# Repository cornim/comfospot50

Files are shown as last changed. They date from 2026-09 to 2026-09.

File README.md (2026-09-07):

<!-- SPDX-FileCopyrightText: 2026 cornim -->
<!-- SPDX-License-Identifier: CC-BY-SA-4.0 -->

# ComfoSpot 50 Home Assistant integration

This project integrates a ComfoSpot 50 into Home Assistant through a custom
ESPHome component and a custom-designed PCB board. The component connects an
ESP32-C3 to the existing panel, reading its LEDs and electrically simulating
short and long presses of the `+` and `-` buttons.

The component is in `components/comfospot/`. Complete ESPHome examples are in
`examples/`, installation and troubleshooting documentation is in `docs/`, and
wiring and the controller board design are in `hardware/`.

## Installation

See [`docs/installation.md`](docs/installation.md) for software flashing, board
power selection, hardware installation, security, and safety instructions.

## Safety and no warranty

This project is provided "as is", without warranty of any kind, express or
implied, including but not limited to warranties of merchantability, fitness
for a particular purpose, safety, and non-infringement. Use of this project
may involve electrical, fire, ventilation, property-damage, personal-injury,
or equipment-damage risks. You are responsible for verifying the design,
electrical compatibility, isolation, installation, operation, and compliance
with applicable laws and regulations.

Do not connect this circuit to a ventilation appliance or mains-related
equipment unless the installation has been reviewed and performed by a
suitably qualified person. Verify voltage levels, current limits, isolation,
grounding, enclosure requirements, and failure behavior before construction or
use. This project is not a safety control and must not be used where its
failure could create an unsafe condition.

## Unofficial project

This is an independent project and is not affiliated with, endorsed by, or
approved by Zehnder Group. "Zehnder" and "ComfoSpot" are trademarks of their
respective owners and are used only to identify the compatible product.

The original idea for this project and the reverse engineering of the ComfoSpot
50 were done by [lorenzspenger](https://github.com/lorenzspenger) in the
[`comfospot-50`](https://github.com/lorenzspenger/comfospot-50) project. This
repository's implementation was built from scratch because the original project
does not support standby mode.

## Fan levels

The fan exposes four active levels plus standby:

- `0`: standby, fans off
- `1` through `4`: the four ComfoSpot fan levels

In Home Assistant, standby is represented by the fan being off. The diagnostic
`Current Fan Speed` sensor reports the last confirmed numeric level `0` through
`4`. It remains unavailable only while the panel's display state is ambiguous,
such as immediately after boot with all LEDs off; it keeps reporting the last
known active speed while the display is temporarily dark for energy-saving mode.

The component reads the physical panel during boot and does not turn the unit
on automatically. Physical short button presses are synchronized back to Home
Assistant. Remote commands read and validate the panel directly, retrying when
the first press only wakes a sleeping display. Direction changes use the
observed panel marker and a bounded long-press operation. Filter runtime counts
confirmed active fan time and is persisted periodically and after a confirmed
filter reset.

## Hardware

The controller board design and detailed panel wiring documentation are in
[`hardware/README.md`](hardware/README.md) and
[`hardware/wiring.md`](hardware/wiring.md).

## Getting hardware

Detailed instructions for ordering the controller board are in
[`hardware/HOW_TO_ORDER.md`](hardware/HOW_TO_ORDER.md). The minimum
order is five boards, so if you need fewer boards, or if you have additional
boards to sell, feel free to open an issue in this repository to arrange a
purchase or sale.

## ESPHome configuration

The example downloads the component from this repository's `main` branch:

```yaml
external_components:
  - source:
      type: git
      url: https://github.com/cornim/comfospot50
      ref: main
    components: [comfospot]
```

See `examples/comfospot.yaml` for a complete example. It requires encrypted
API access, an OTA password, Wi-Fi credentials, and a non-empty fallback access
point password supplied through a local `examples/secrets.yaml`. Never commit
that file or any other deployment secrets.

## Building and testing

Build and run the host-side tests with:

```text
cmake -S . -B build
cmake --build build
ctest --test-dir build --output-on-failure
```

The live ESPHome API test runner is an optional Python end-to-end test suite in
`tests/e2e_comfospot.py`. It connects to a flashed ComfoSpot device over the
native ESPHome API, discovers its entities, exercises fan controls and state
reporting, and records a test report and device logs. It requires the
development dependency listed in `requirements-dev.txt`. The runner uses
credentials supplied through environment variables and never stores the API key
in test artifacts. See [`docs/e2e-testing.md`](docs/e2e-testing.md) for setup
and usage.

## Repository licensing

- ESPHome component source and tests: `GPL-3.0-or-later`.
- Project-authored schematic, PCB layout, wiring diagram, and hardware design:
  `CERN-OHL-S-2.0`.
- Project-authored documentation and timing notes: `CC-BY-SA-4.0`.
- Embedded component-library data and any other third-party material remain
  subject to their applicable terms; see `THIRD_PARTY_NOTICES.md`.

The project copyright holder is [`cornim`](https://github.com/cornim).
Licensing, security, and contribution questions are handled through GitHub for
this repository.

The license files are in `LICENSES/`. The root `LICENSE` is the GPLv3-or-later
license used for the software portion of the repository. The scoped notices in
the hardware and documentation directories define the other scopes.

No manufacturer datasheet PDFs or product manuals are distributed by this
repository. Consult the relevant manufacturer or distributor for current
documentation.

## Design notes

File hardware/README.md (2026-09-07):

<!-- SPDX-FileCopyrightText: 2026 cornim -->
<!-- SPDX-License-Identifier: CERN-OHL-S-2.0 -->

# Hardware

The schematic and PCB in this directory are the project-authored controller
board design. The board is intended to interface an ESP32-C3 with the existing
ComfoSpot panel.
See [`wiring.md`](wiring.md) for the panel connections and electrical interface
notes.

## License scope

The project-authored schematic connectivity, PCB layout, routing, board
outline, wiring diagram, and related hardware documentation are released under
the CERN Open Hardware Licence Version 2 - Strongly Reciprocal, found in
`../LICENSES/CERN-OHL-S-2.0.txt`.

The KiCad files contain embedded component symbols and footprints selected from
the JLCPCB/LCSC/EasyEDA component ecosystem and Würth's component library.
Those embedded third-party elements are not relicensed by the project license.
Their provenance and applicable terms are described in
`../THIRD_PARTY_NOTICES.md`.

The standard KiCad library elements used by the design remain subject to the
KiCad library license and its design exception.

The project copyright holder is [`cornim`](https://github.com/cornim).
Licensing and contribution questions can be handled through GitHub for this
repository.

Source location for the covered hardware design is the GitHub repository
containing this file. Preserve this source location and the applicable notices
when conveying the hardware design or a product made from it.

## Deliberate omissions

3D model references are not included in the public PCB file. This keeps the
design portable and avoids distributing model files that are not needed for
schematic review, PCB editing, or fabrication. The board remains a complete
2D KiCad design and retains its footprints, pads, nets, routing, vias, zones,
silkscreen, and outline.

Manufacturer datasheet PDFs are not included. Use the manufacturer or
distributor source for current component documentation. The LCSC identifiers
in the BOM are retained as manufacturing-selection information.

The `hardware/production/comfospot50_full.zip` archive contains Gerber and
drill fabrication output. It is generated output and does not contain the
component library or 3D model files.

## Safety and no warranty

The hardware is provided "as is", without warranty of any kind, express or
implied, including warranties of merchantability, fitness for a particular
purpose, safety, and non-infringement. Verify voltage levels, current limits,
isolation, grounding, enclosure requirements, creepage, clearance, and failure
behavior before construction or use. A qualified person must review and
perform any connection to an installed ventilation appliance or mains-related
equipment.

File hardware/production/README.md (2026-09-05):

<!-- SPDX-FileCopyrightText: 2026 cornim -->
<!-- SPDX-License-Identifier: CERN-OHL-S-2.0 -->

# Production Output

The Gerber and drill archive is generated from the project hardware design.
The LCSC identifiers in `bom.csv` identify the selected manufacturing parts;
they are not a license for third-party CAD or datasheet material.

The production outputs are provided without warranty. Verify the board stackup,
component substitutions, assembly orientation, electrical clearances, and
applicable manufacturing requirements before ordering.

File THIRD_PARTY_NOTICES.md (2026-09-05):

<!-- SPDX-FileCopyrightText: 2026 cornim -->
<!-- SPDX-License-Identifier: CC-BY-SA-4.0 -->

# Third-Party Notices

The project licenses apply only to project-authored material within the scope
described in `README.md`, `hardware/README.md`, and the source-file notices.
Third-party material remains subject to its own terms.

## JLCPCB, LCSC, and EasyEDA component data

The KiCad schematic and PCB contain embedded symbols and footprints originating
from or based on component data available through the JLCPCB/LCSC/EasyEDA
ecosystem. The following LCSC identifiers are retained as component-selection
and manufacturing references:

```text
C25804       UNI-ROYAL 0603WAF1002T5E
C106214      YAGEO CC0603KRX5R6BB105
C14663       YAGEO CC0603KRX7R9BB104
C13585       Samsung CL31A106KBHNNNE
C5672        Samsung CL31A226KPHNNNE
C2944070     Espressif ESP32-C3-WROOM-02-H4
C5369647     YLPTEC K7803-1000R3
C976701      KEFA KF239-5.08-2P
C82942       MICRONE ME6211C33M5G-N
C963206      G-Switch MK-12C02-G020
C114765      YAGEO RC0402FR-0722RL
C269716      Tyohm RMC06035.1K1%N
C18384       Littelfuse RXEF030
C2482        MDD SS110
C318884      XKB TS-1187A-B-A-B
C393939      SHOU HAN TYPE-C16PIN
C7519        ST USBLC6-2SC6
```

The identifiers and component names do not constitute a license to reproduce
the source library data. No JLCPCB/LCSC/EasyEDA datasheet PDFs are distributed
here. Obtain current component documentation directly from the applicable
manufacturer or distributor.

Relevant source and terms pages include:

- [EasyEDA Terms and Conditions](https://easyeda.com/page/legal)
- [LCSC Terms and Conditions](https://www.lcsc.com/help/terms-and-conditions)
- [JLCPCB Terms and Conditions](https://jlcpcb.com/help/article/Terms-%26-Conditions)
- [easyeda2kicad converter](https://github.com/uPesy/easyeda2kicad.py), licensed separately under AGPL-3.0

The converter's license applies to the converter software, not automatically to
component data retrieved through the converter.

## Würth Elektronik library data

The two WR-MM connector footprints and their embedded symbol data correspond to
the official Würth Elektronik KiCad library:

- [Würth Elektronik KiCad Library](https://github.com/WurthElektronik/KiCad-Library)
- [License terms](https://github.com/WurthElektronik/KiCad-Library/blob/master/License_Terms_WE_KiCad_library.pdf)
- [Disclaimer](https://github.com/WurthElektronik/KiCad-Library/blob/master/Disclaimer_WE_KiCad_library.pdf)

The source repository was inspected at commit
`40adcee44afdab5f4ed8038699f78bd784e0f594` on 2026-09-04. The exact upstream
files matching the connector identifiers were present at that revision.

The relevant parts are:

```text
J_Wurth_WR-MM_690357101472
J_Wurth_WR-MM_690368171472
```

Würth retains ownership of its models. Its terms permit creating and sharing
designs using the models, subject to the separate license terms, but do not
grant a general patent, trademark, or unrestricted sublicensing license. Any
Würth model or library file distributed separately must retain the applicable
Würth notices and must be clearly marked if modified.

## KiCad libraries

The standard KiCad elements used by the project include `power:GND` and the
standard test-point symbol and footprint. KiCad libraries are licensed under
CC BY-SA 4.0 with an exception for electronic designs and generated files that
use the library data.

- [KiCad library license](https://www.kicad.org/libraries/license/)

## Build-time software dependencies

The ESPHome component is intended to be built by ESPHome and is not a copy of
ESPHome itself. ESPHome is available from
[its repository](https://github.com/esphome/esphome) under the MIT License.

The live test runner uses `aioesphomeapi`, declared in
`requirements-dev.txt`. It is available from
[its repository](https://github.com/esphome/aioesphomeapi) under the MIT
License. These dependencies are obtained by users or CI and are not bundled
in this repository.

## Project copyright and contact

Project copyright holder: [`cornim`](https://github.com/cornim). Licensing
questions and notices can be submitted through GitHub for this repository.

## Manufacturer names and trademarks

Manufacturer names, product names, part numbers, and trademarks identify the
components compatible with the design. They do not imply endorsement or
affiliation. Zehnder and ComfoSpot are trademarks of their respective owners.

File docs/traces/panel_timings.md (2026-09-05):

<!-- SPDX-FileCopyrightText: 2026 cornim -->
<!-- SPDX-License-Identifier: CC-BY-SA-4.0 -->

# ComfoSpot Panel Timings

These timings were measured on the live ComfoSpot panel through the ESPHome
verbose scan log. The panel was sampled every 50 ms, so individual transition
timestamps have an uncertainty of approximately one scan interval. Times in
each measurement are relative to the start of that monitor run.

## Measurement 1: Normal Button Press

One physical `+` press was monitored while the panel was active.

| Event | Time |
| --- | ---: |
| Button pressed | 5.832 s |
| Button released | 6.152 s |
| Button duration | 0.319 s |
| Fan LEDs on | 6.195 s |
| Fan LEDs off | 15.237 s |
| Fan LED duration | 9.043 s |

LED mask sequence:

```text
0x00 -> 0x01 -> 0x00
```

The LED indication started approximately 43 ms after the button release.

## Measurement 2: Wake From Standby

One short physical `+` press woke the panel from standby. The standby wake
acknowledgement lights all four fan LEDs.

| Event | Time |
| --- | ---: |
| Button pressed | 5.072 s |
| Button released | 5.278 s |
| Button duration | 0.206 s |
| All fan LEDs on (`0x0F`) | 5.278 s |
| All fan LEDs off (`0x00`) | 6.467 s |
| All-LED duration | 1.189 s |

LED mask sequence:

```text
0x00 -> 0x0F -> 0x00
```

The all-LED frame started at the observed button-release transition, within
the 50 ms measurement resolution.

## Measurement 3: Standby Wake and Intake

The panel was first woken with a short `+` press and then changed to Intake
with a long `+` press.

### Button timings

| Press | Start | End | Duration |
| --- | ---: | ---: | ---: |
| Wake press (`+`) | 6.955 s | 7.120 s | 0.166 s |
| Intake press (`+`) | 7.689 s | 15.777 s | 8.088 s |

### Fan LED transitions

| Time | Transition |
| ---: | --- |
| 7.178 s | `0x00 -> 0x03` |
| 15.198 s | `0x03 -> 0x08` |
| 15.664 s | `0x08 -> 0x00` |
| 16.184 s | `0x00 -> 0x08` |
| 16.689 s | `0x08 -> 0x00` |
| 17.266 s | `0x00 -> 0x08` |
| 17.726 s | `0x08 -> 0x00` |
| 18.182 s | `0x00 -> 0x03` |
| 21.220 s | `0x03 -> 0x08` |
| 21.629 s | `0x08 -> 0x00` |

The primary Intake marker started 7.509 s after the long press began, or
0.579 s before it was released. The first marker sequence returned to the
normal Speed-2 display (`0x03`) 2.405 s after the long press was released.

Relative to the end of the long press:

| Relative time | Transition |
| ---: | --- |
| -0.579 s | `0x03 -> 0x08` |
| -0.113 s | `0x08 -> 0x00` |
| +0.407 s | `0x00 -> 0x08` |
| +0.912 s | `0x08 -> 0x00` |
| +1.489 s | `0x00 -> 0x08` |
| +1.949 s | `0x08 -> 0x00` |
| +2.405 s | `0x00 -> 0x03` |
| +5.443 s | `0x03 -> 0x08` |
| +5.852 s | `0x08 -> 0x00` |

The normal Speed-2 display is `0x03`; the Intake marker is `0x08` alternating
with `0x00`.

## Measurement 4: Intake to Exchange

The panel was woken with a short `+` press and then changed from Intake back to
Exchange with a long `+` press.

### Button timings

| Press | Start | End | Duration |
| --- | ---: | ---: | ---: |
| Wake press (`+`) | 3.798 s | 4.004 s | 0.207 s |
| Exchange press (`+`) | 4.616 s | 12.675 s | 8.059 s |

### Fan LED transitions

| Time | Transition |
| ---: | --- |
| 4.004 s | `0x00 -> 0x03` |
| 4.313 s | `0x03 -> 0x08` |
| 4.768 s | `0x08 -> 0x00` |
| 5.330 s | `0x00 -> 0x08` |
| 5.832 s | `0x08 -> 0x00` |
| 6.353 s | `0x00 -> 0x08` |
| 6.862 s | `0x08 -> 0x00` |
| 7.332 s | `0x00 -> 0x03` |
| 19.302 s | `0x03 -> 0x00` |

The Intake marker sequence completed before the long press ended. The normal
Speed-2 display returned 5.343 s before release and remained visible for
6.627 s afterward. The later `0x03 -> 0x00` transition occurred 6.627 s after
release, when the display entered Energy-Saving mode.

LED mask sequence:

```text
0x00 -> 0x03 -> 0x08 -> 0x00 -> 0x08 -> 0x00
     -> 0x08 -> 0x00 -> 0x03 -> 0x00
```

No `0x0F` all-LED standby acknowledgement was observed in this measurement.

## Measurement 5: Speed 2 to Speed 1 and Energy-Saving

The panel was woken with a short `-` press and then reduced from Speed 2 to
Speed 1 with a short `-` press. The measurement ended when the display entered
Energy-Saving mode.

### Button timings

| Press | Start | End | Duration |
| --- | ---: | ---: | ---: |
| Wake press (`-`) | 3.082 s | 3.238 s | 0.156 s |
| Speed reduction (`-`) | 3.963 s | 4.064 s | 0.101 s |

### Fan LED transitions

| Time | Transition |
| ---: | --- |
| 3.238 s | `0x00 -> 0x03` |
| 4.064 s | `0x03 -> 0x01` |
| 13.296 s | `0x01 -> 0x00` |

The Speed-1 display (`0x01`) remained visible for 9.232 s after the second
button was released. The display then entered Energy-Saving mode at 13.296 s.

LED mask sequence:

```text
0x00 -> 0x03 -> 0x01 -> 0x00
```

## Summary

| Scenario | Button behavior | Relevant panel timing |
| --- | --- | --- |
| Normal press | One short press, 0.319 s | `0x01` appeared 43 ms after release and lasted 9.043 s |
| Standby wake | One short press, 0.206 s | `0x0F` appeared immediately and lasted 1.189 s |
| Wake to Intake | Wake 0.166 s, long press 8.088 s | Intake marker began 7.509 s after long-press start; normal display returned 2.405 s after release |
| Intake to Exchange | Wake 0.207 s, long press 8.059 s | Intake marker completed before release; normal display remained 6.627 s after release |
| Speed 2 to 1 | Wake 0.156 s, short press 0.101 s | Speed-1 display lasted 9.232 s before Energy-Saving |

## Interpretation

- A normal short press is approximately 0.1 to 0.3 s in these measurements.
- The observed long direction press is approximately 8.1 s.
- The Intake marker begins approximately 7.5 s after the long press starts.
- The direction marker alternates a single LED with the all-off mask. Intake
  uses `0x08`; Exhaust uses `0x01` on the observed hardware.
- Standby wake uses a distinct all-four-LED frame (`0x0F`) lasting about 1.2 s.
- After a speed change, the active speed display remains lit for about 9.2 s
  before entering Energy-Saving mode.

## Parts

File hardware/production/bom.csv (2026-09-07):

Designator | Footprint | Quantity | Value | LCSC Part #
CN1 | CONN-TH_4P-P3.5-2601-3102 | 1 | 2601-3102 | C20252913
C_3V3_BULK1 | C1206 | 1 | 22uF 10V | C5672
C_3V3_BYP1, C_ESPIN_BYP1, C_IN_BYP1 | C0603 | 3 | 100nF | C14663
C_ESP32_BYP1 | C0603 | 1 | 1uF | C106214
C_IN_BULK1 | C1206 | 1 | 10uF 50V | C13585
D_REV1 | SMA_L4.3-W2.6-LS5.2-RD | 1 | Schottky | C2482
D_USB_ESD1 | SOT-23-6_L2.9-W1.6-P0.95-LS2.8-BL | 1 | USB ESD | C7519
F1 | FUSE-TH_L7.4-W3.0-P5.10-D0.6-S1.20 | 1 | PTC 0.30A | C18384
J_USB1 | USB-C-SMD_TYPE-C16PIN | 1 | USB-C | C393939
R_CC1, R_CC2 | R0603 | 2 | 5k1 | C269716
R_CFG1, R_CFG2, R_CFG3, R_CFG4 | R0603 | 4 | 10k | C25804
R_USB_DN1, R_USB_DP1 | R0402 | 2 | 22R | C114765
SW_BOOT1 | SW-SMD_4P-L5.1-W5.1-P3.70-LS6.5-TL_H1.5 | 1 | BOOT | C318884
SW_RESET1 | SW-SMD_4P-L5.1-W5.1-P3.70-LS6.5-TL_H1.5 | 1 | RESET | C318884
SW_V24_USB1 | SW-SMD_MK-12C02-G020 | 1 | V24_USB | C963206
TP_3V3 | TestPoint_Pad_D2.0mm | 1 | 3V3
TP_GND1 | TestPoint_Pad_D2.0mm | 1 | GND
U1 | WIFIM-SMD_18P-L20.0-W18.0-P1.50 | 1 | ESP32-C3-WROOM-02-H4 | C2944070
U_24V_3V3 | PWRM-TH_YLPTEC_K78XX-1000R3 | 1 | 3.3V REG | C5369647
U_3V3_LDO1 | SOT-23-5_L3.0-W1.7-P0.95-LS2.8-BL | 1 | 3.3V LDO | C82942

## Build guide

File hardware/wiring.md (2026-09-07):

<!-- SPDX-FileCopyrightText: 2026 cornim -->
<!-- SPDX-License-Identifier: CERN-OHL-S-2.0 -->

# Wiring

The included examples target an ESP32-C3. The panel GPIO mapping is hardcoded
in the component and matches `comfospot50_full.kicad_sch`:

| ESP32 pin | Panel signal | Function |
| --- | --- | --- |
| IO0 | `led_1` | Fan LED 1 |
| IO1 | `led_3` | Fan LED 3 |
| IO3 | `led_2` | Fan LED 2 |
| IO4 | `led_4` | Fan LED 4 |
| IO5 | `btn_plus` | Panel `+` button |
| IO6 | `btn_minus` | Panel `-` button |
| IO7 | `led_err` | Error LED |
| IO10 | `led_filter` | Filter warning LED |
| TX0 / IO21 | `led_auto` | Automatic-mode LED |

All panel LED inputs use inverted logic with pull-ups. The button connections
use inverted open-drain-style logic. `led_auto` is reported by the diagnostic
`Automatic Mode LED` binary sensor.

The component is restricted to the ESP32-C3 mapping above. Configure the
logger as `USB_SERIAL_JTAG` or `USB_CDC`; UART0/TX0 must not drive IO21 because
IO21 is used as the automatic-mode LED input.

## No warranty and safety

This hardware is provided "as is", without warranty of any kind, express or
implied, including warranties of merchantability, fitness for a particular
purpose, safety, and non-infringement. Verify voltage levels, current limits,
isolation, grounding, enclosure requirements, creepage, clearance, and failure
behavior before construction or use.

Do not connect this circuit to a ventilation appliance or mains-related
equipment unless the installation has been reviewed and performed by a
suitably qualified person. This project is independent and is not affiliated
with, endorsed by, or approved by Zehnder Group.

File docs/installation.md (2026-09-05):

<!-- SPDX-FileCopyrightText: 2026 cornim -->
<!-- SPDX-License-Identifier: CC-BY-SA-4.0 -->

# Installation

## Board power selection

The controller board has a power-source switch with `USB` and `24V`
positions. Select the power source before connecting it:

- For USB flashing, disconnect the 24 V supply and set the switch to `USB`
  before connecting the USB cable. The ESP32 is not powered from USB unless
  the switch is in this position.
- For normal operation, disconnect the USB cable, set the switch to `24V`,
  and then connect the 24 V supply.
- Never connect USB and 24 V at the same time.

## Software

The ESPHome firmware must be compiled and flashed onto the ESP32 before the
controller can operate. Install ESPHome or use the ESPHome add-on in Home
Assistant. Copy `examples/comfospot.yaml` for a local installation and
configure the device name. The panel GPIO mapping is fixed by the component.
Create `examples/secrets.yaml` with your own values:

```yaml
wifi_ssid: My SSID
wifi_password: My Wi-Fi password
api_encryption_key: My API encryption key
ota_password: My OTA password
fallback_ap_password: My fallback hotspot password (8+ characters)
```

With the 24 V supply disconnected and the board switch in the `USB` position,
connect USB and run:

```text
esphome run examples/comfospot.yaml
```

ESPHome may enter download mode automatically. If it cannot connect to the
board or the upload fails, leave USB connected and powered, then use the
board's buttons to enter download mode: hold `BOOT`, press and release `RESET`
once, and then release `BOOT`. Retry the command after entering download mode.
For more detail about ESP32-C3 USB flashing and manual download mode, see
Espressif's [ESP32-C3 serial connection instructions](https://docs.espressif.com/projects/esp-idf/en/latest/esp32c3/get-started/establish-serial-connection.html).

After the firmware has been flashed successfully, disconnect USB, move the
switch to `24V`, and connect the 24 V supply. Subsequent firmware updates can
use ESPHome OTA with USB disconnected and the switch in the `24V` position.

The example requires all five values shown above when built directly with the
`esphome` CLI.

The YAML and C++ source are build-time inputs. The ESP32 receives one compiled
firmware image; documentation and source files are not uploaded to it.

## Hardware

### Prepare the custom board

Before starting the hardware installation, solder the two Würth connectors to
the custom board:

- Solder the female connector into the `CABLE1` position.
- Solder the male connector into the `PANEL1` position.
- Install and solder both connectors on the side of the board marked with the
  corresponding reference text. Solder all connector pins and verify that the
  connectors are fully seated and aligned.

The male connector in `PANEL1` plugs directly into the back panel of the
ComfoSpot 50. The original panel cable is then plugged into the female
`CABLE1` connector on the custom board.

### Install the board

The ComfoSpot 50 main control board is on the side of the unit under a thin
plastic cover. Pull the cover off gently to expose the main control board.

1. Disconnect the custom board from USB.
2. Set the custom board's power switch to `24V`.
3. Ensure that the 24 V supply is disconnected while changing the appliance
   wiring.
4. Locate the power cable on the side of the main control board furthest from
   the panel and remove it from the original power-supply input.
5. Split the existing 24 V supply using suitable connectors. WAGO 221-413
   clamps are one example; equivalent connectors rated for the wiring and
   circuit may also be used. Use one connector for each power conductor,
   preserving the polarity. From the connectors, run two cables back to the
   original power-supply input of the ComfoSpot main control board and two
   cables to the custom board's `24V IN` connector.
6. Remove the original panel cable from the back panel of the ComfoSpot 50.
7. Plug the custom board's `PANEL1` connector directly into the back panel.
8. Plug the removed panel cable into the custom board's `CABLE1` connector.

Check the wiring and polarity before restoring the 24 V supply. USB and 24 V
must never be connected at the same time.

## Security

Use encrypted ESPHome API access and a non-empty OTA password for installations
connected to a real network. Do not commit `secrets.yaml` or distribute shared
credentials.

## Safety

The software and hardware are provided "as is", without warranty of any kind.
Verify the electrical interface, voltage levels, isolation, grounding, and
failure behavior before connecting an ESP32 to an installed ventilation
appliance. Any appliance or mains-related work must be reviewed and performed
by a suitably qualified person.

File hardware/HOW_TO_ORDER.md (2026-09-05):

<!-- SPDX-FileCopyrightText: 2026 cornim -->
<!-- SPDX-License-Identifier: CERN-OHL-S-2.0 -->

# How to Order Hardware

To order new controller boards, use the following process with JLCPCB:

1. Go to [jlcpcb.com](https://jlcpcb.com) and click **Get an Instant Quote**.
2. Upload the complete Gerber ZIP archive from
   `hardware/production/comfospot50_full.zip`. This archive contains the Gerber
   files generated for production.
3. Scroll down and select **PCB assembly**.
4. Click **Next**.
5. Upload the BOM file, `hardware/production/bom.csv`, and the positions file,
   `hardware/production/positions.csv`.
6. Click **Process, BOM, and CPL**.
7. Select all of the parts that you want to use. Most parts should be selected
   automatically. For some parts, you only need to click the **Select** checkbox.

## Unmatched components

Typically, the only component that appears in **Unmatched components** is the
`U_24V_3V3` buck converter. To match it:

1. Take the part number for `U_24V_3V3` from the BOM file.
2. Search for that part number in the JLCPCB component selector.
3. Select the matching part.

Leave the other unmatched components, such as the test points and possibly the
cable and panel connectors from Wuerth, unmatched. When you click **Next**, select
**Don't place** for those components.

After that, follow the remaining JLCPCB ordering process, pay, and place the
order.

## Minimum order and surplus boards

The minimum order quantity is five boards. At the time of writing, five boards
cost approximately EUR 125, plus the Wuerth connectors that must be ordered
separately. Prices and availability can change, so check the current total
before ordering.

If you only need one or two boards, it may make sense to buy the remaining
boards from someone who has already placed a five-board order. If you ordered
five boards but do not need all of them, you can offer the surplus boards to
someone else. For either purpose, feel free to open an issue in this GitHub
repository to find someone who wants to buy or sell additional boards.

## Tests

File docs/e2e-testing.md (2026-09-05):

<!-- SPDX-FileCopyrightText: 2026 cornim -->
<!-- SPDX-License-Identifier: CC-BY-SA-4.0 -->

# Live End-to-End Testing

`tests/e2e_comfospot.py` is a live test runner for a flashed ComfoSpot node.
It connects through the native ESPHome API, discovers entity keys at runtime,
subscribes to INFO-level device logs and state updates, drives fan speeds and
directions, records evidence, and attempts to leave the fan in standby when the
suite ends.

The runner does not store or print the API key. Supply it through the
`ESPHOME_API_KEY` environment variable or `--api-key`. The host can be supplied
through `COMFOSPOT_HOST` or `--host`.

## Prerequisites

The runner is compatible with the deployment's INFO logger level:

```yaml
logger:
  level: INFO
  hardware_uart: USB_SERIAL_JTAG
```

Install the API client if it is not already available:

```text
python3 -m pip install -r requirements-dev.txt
```

## Safe API-Driven Run

Run the complete non-physical suite with:

```text
ESPHOME_API_KEY='...' COMFOSPOT_HOST=comfospot.local \
  python3 tests/e2e_comfospot.py
```

The default run includes API connectivity/entity/state checks, standby-to-speed
1 and standby-to-speed 4 cycles, the six requested direction transitions with
the panel active at a non-zero speed, runtime accounting, and API reconnect.
Each standby speed cycle waits 30 seconds after the fan-off state is observed
before waking the panel. Direction changes are not tested from standby,
power-saving, or a separate running condition: the panel only accepts direction
changes while ventilation is active, and the controller owns the wake/display
preparation. The runner writes `report.json` and `logs.txt` under
`/tmp/comfospot-e2e` by default. The key is not written to either file.

The narrowed suite can be run in bounded batches using shell-style test ID
patterns. This is useful because direction and speed operations intentionally
wait for real panel confirmation:

```text
ESPHOME_API_KEY='...' COMFOSPOT_HOST=comfospot.local \
  python3 -u tests/e2e_comfospot.py --tests 'API-*,FAN-*'

ESPHOME_API_KEY='...' COMFOSPOT_HOST=comfospot.local \
  python3 -u tests/e2e_comfospot.py --tests 'DIR-PANEL-ON,RUN-*'
```

List the complete inventory without connecting:

```text
python3 tests/e2e_comfospot.py --host unused --api-key unused --list-tests
```

Every direction transition explicitly starts from a visibly active speed-2
display. The firmware itself also enforces this rule: if the panel is dark, it
sends a short wake tap and waits for the energy-saving wake or standby
acknowledgement to finish before applying the long direction hold.

The process exits nonzero if any executed test fails. It always attempts a
final fan-off command before disconnecting.

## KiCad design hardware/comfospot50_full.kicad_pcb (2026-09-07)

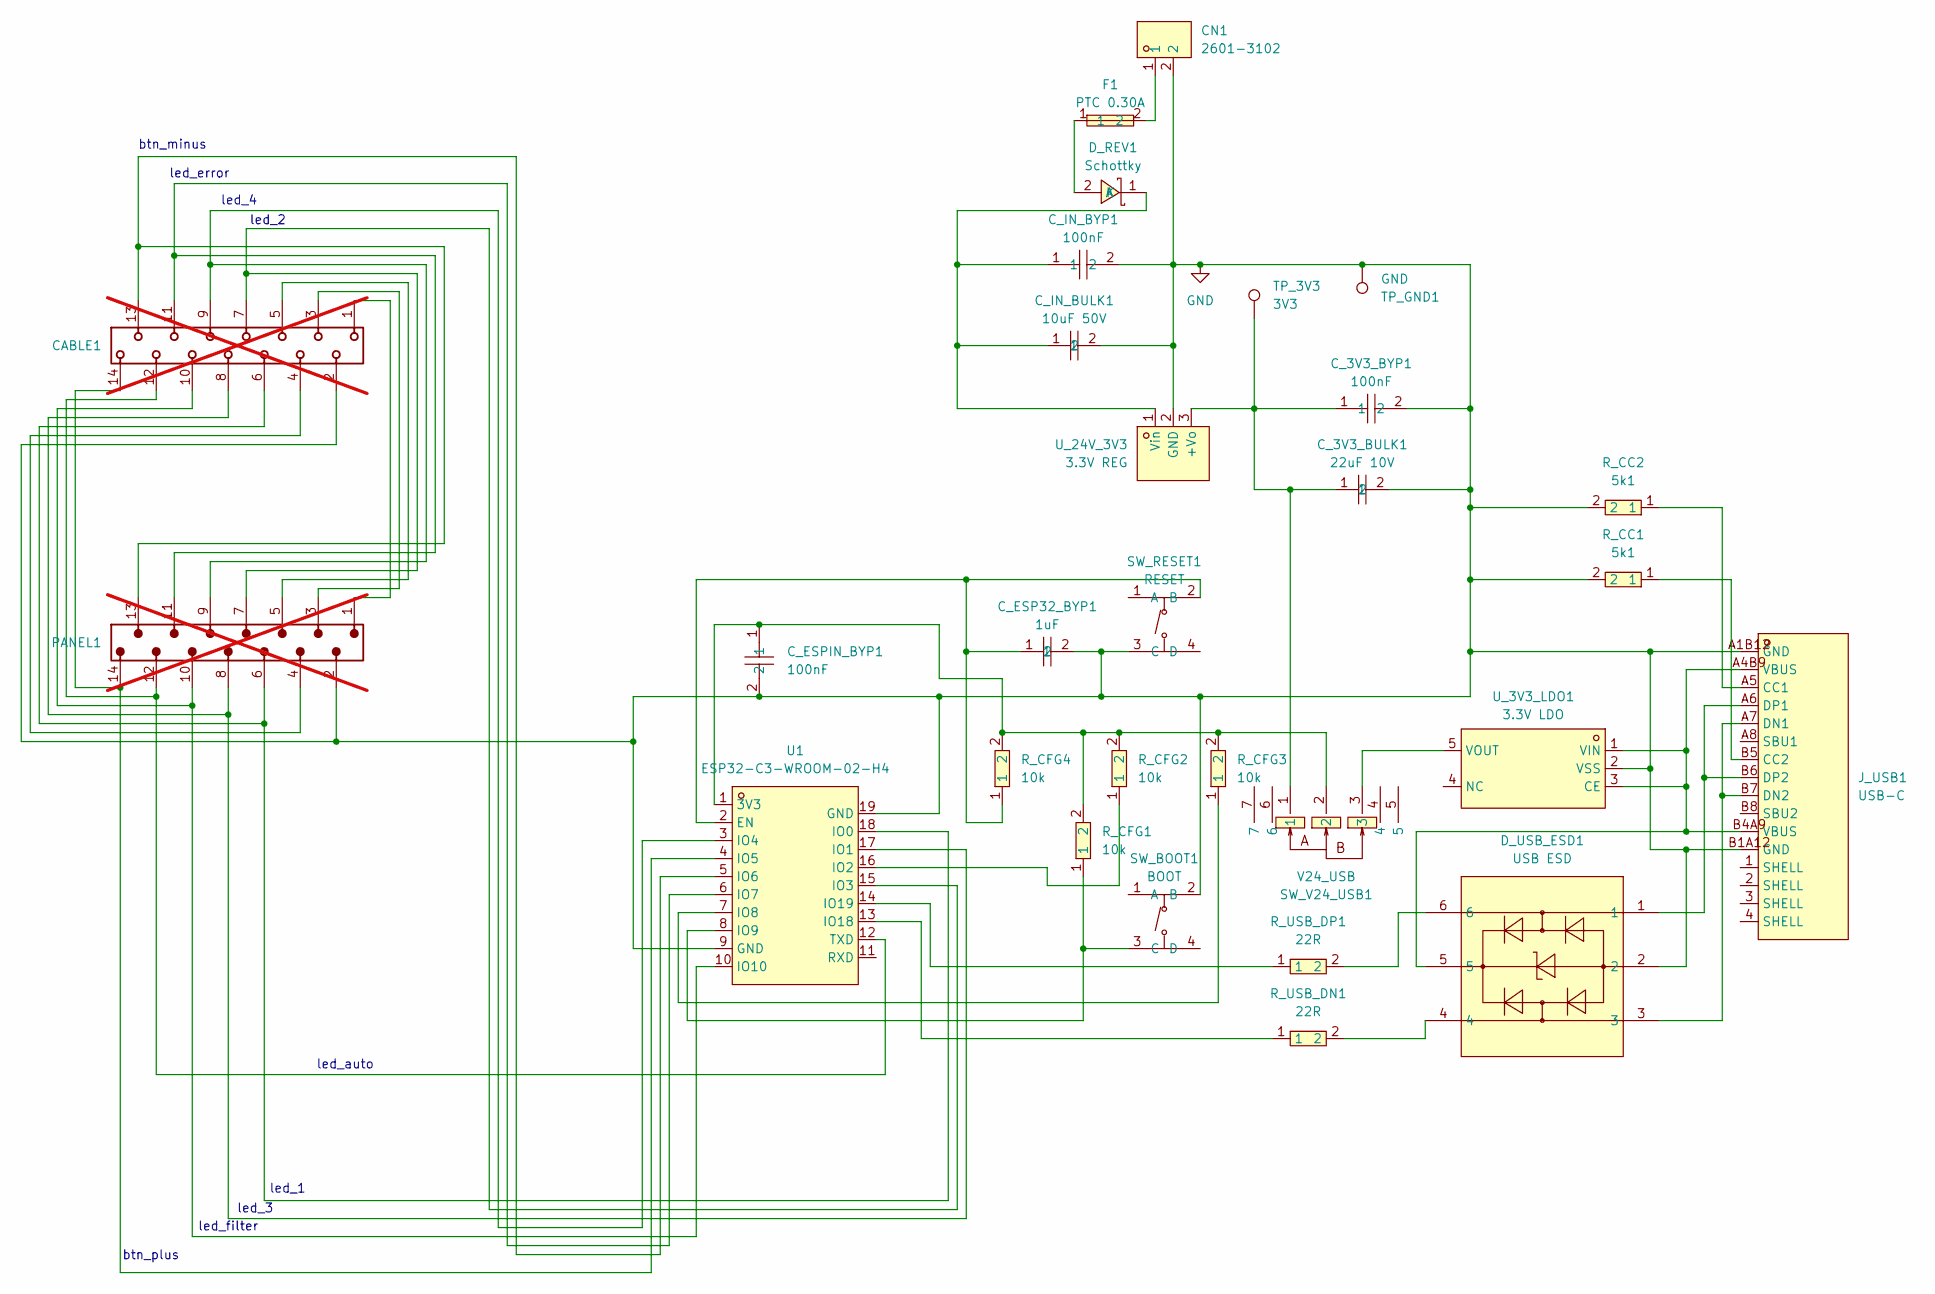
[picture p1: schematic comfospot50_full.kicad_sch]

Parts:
CABLE1: 14-pin F; J_Wurth_WR-MM_690368171472; Working Voltage (V (AC)) 250; not fitted
CN1: 2601-3102; CONN-TH_4P-P3.5-2601-3102; MPN 2601-3102; LCSC Part C20252913
C_3V3_BULK1: 22uF 10V; C1206; MPN CL31A226KPHNNNE; LCSC Part C5672
C_3V3_BYP1: 100nF; C0603; MPN CC0603KRX7R9BB104; LCSC Part C14663
C_ESP32_BYP1: 1uF; C0603; MPN CC0603KRX5R6BB105; LCSC Part C106214
C_ESPIN_BYP1: 100nF; C0603; MPN CC0603KRX7R9BB104; LCSC Part C14663
C_IN_BULK1: 10uF 50V; C1206; MPN CL31A106KBHNNNE; LCSC Part C13585
C_IN_BYP1: 100nF; C0603; MPN CC0603KRX7R9BB104; LCSC Part C14663
D_REV1: Schottky; SMA_L4.3-W2.6-LS5.2-RD; MPN SS110; LCSC Part C2482
D_USB_ESD1: USB ESD; SOT-23-6_L2.9-W1.6-P0.95-LS2.8-BL; MPN USBLC6-2SC6; LCSC Part C7519
F1: PTC 0.30A; FUSE-TH_L7.4-W3.0-P5.10-D0.6-S1.20; MPN RXEF030; LCSC Part C18384
J_USB1: USB-C; USB-C-SMD_TYPE-C16PIN; MPN TYPE-C16PIN; LCSC Part C393939
PANEL1: 14-pin M; J_Wurth_WR-MM_690357101472; not fitted
R_CC1, R_CC2: 5k1; R0603; MPN RMC06035.1K1%N; LCSC Part C269716
R_CFG1, R_CFG2, R_CFG3, R_CFG4: 10k; R0603; MPN 0603WAF1002T5E; LCSC Part C25804
R_USB_DN1: 22R; R0402; MPN RC0402FR-0722RL; LCSC Part C114765
R_USB_DP1: 22R; R0402; MPN RC0402FR-0722RL; LCSC Part C114765
SW_BOOT1: BOOT; SW-SMD_4P-L5.1-W5.1-P3.70-LS6.5-TL_H1.5; MPN TS-1187A-B-A-B; LCSC Part C318884
SW_RESET1: RESET; SW-SMD_4P-L5.1-W5.1-P3.70-LS6.5-TL_H1.5; MPN TS-1187A-B-A-B; LCSC Part C318884
SW_V24_USB1: V24_USB; SW-SMD_MK-12C02-G020; MPN MK-12C02-G020; LCSC Part C963206
TP_3V3: 3V3; TestPoint_Pad_D2.0mm
TP_GND1: GND; TestPoint_Pad_D2.0mm
U1: ESP32-C3-WROOM-02-H4; WIFIM-SMD_18P-L20.0-W18.0-P1.50; MPN ESP32-C3-WROOM-02-H4; LCSC Part C2944070
U_3V3_LDO1: 3.3V LDO; SOT-23-5_L3.0-W1.7-P0.95-LS2.8-BL; MPN ME6211C33M5G-N; LCSC Part C82942
U_24V_3V3: 3.3V REG; PWRM-TH_YLPTEC_K78XX-1000R3; MPN K7803-1000R3; LCSC Part C5369647

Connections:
GND: CABLE1.2, CN1.2, C_3V3_BULK1.2, C_3V3_BYP1.2, C_ESP32_BYP1.2, C_ESPIN_BYP1.2, C_IN_BULK1.2, C_IN_BYP1.2, D_USB_ESD1.2, J_USB1.A1B12 (GND), J_USB1.B1A12 (GND), PANEL1.2, R_CC1.2, R_CC2.2, SW_BOOT1.2 (B), SW_RESET1.3 (C), TP_GND1.1 (1_1), U1.9 (GND), U1.19 (GND), U_3V3_LDO1.2 (VSS), U_24V_3V3.2 (GND)
unnamed: CABLE1.1, PANEL1.1
unnamed: CABLE1.3, PANEL1.3
unnamed: CABLE1.4, PANEL1.4
unnamed: CABLE1.5, PANEL1.5
unnamed: CN1.1, F1.2
unnamed: D_REV1.2 (A), F1.1
unnamed: C_IN_BULK1.1, C_IN_BYP1.1, D_REV1.1 (K), U_24V_3V3.1 (Vin)
unnamed: D_USB_ESD1.4, R_USB_DN1.2
unnamed: D_USB_ESD1.6, R_USB_DP1.2
unnamed: J_USB1.A5 (CC1), R_CC2.1
unnamed: J_USB1.B5 (CC2), R_CC1.1
unnamed: D_USB_ESD1.3, J_USB1.A7 (DN1), J_USB1.B7 (DN2)
unnamed: D_USB_ESD1.1, J_USB1.A6 (DP1), J_USB1.B6 (DP2)
unnamed: R_CFG1.1, SW_BOOT1.3 (C), U1.8 (IO9)
unnamed: C_ESP32_BYP1.1, R_CFG4.1, SW_RESET1.2 (B), U1.2 (EN)
unnamed: C_ESPIN_BYP1.1, R_CFG1.2, R_CFG2.2, R_CFG3.2, R_CFG4.2, SW_V24_USB1.2, U1.1 (3V3)
unnamed: CABLE1.6, PANEL1.6, U1.18 (IO0)
unnamed: CABLE1.8, PANEL1.8, U1.17 (IO1)
unnamed: R_CFG2.1, U1.16 (IO2)
unnamed: CABLE1.7, PANEL1.7, U1.15 (IO3)
unnamed: CABLE1.9, PANEL1.9, U1.3 (IO4)
unnamed: CABLE1.14, PANEL1.14, U1.4 (IO5)
unnamed: CABLE1.13, PANEL1.13, U1.5 (IO6)
unnamed: CABLE1.11, PANEL1.11, U1.6 (IO7)
unnamed: R_CFG3.1, U1.7 (IO8)
unnamed: CABLE1.10, PANEL1.10, U1.10 (IO10)
unnamed: R_USB_DN1.1, U1.13 (IO18)
unnamed: R_USB_DP1.1, U1.14 (IO19)
unnamed: CABLE1.12, PANEL1.12, U1.12 (TXD)
unnamed: D_USB_ESD1.5, J_USB1.A4B9 (VBUS), J_USB1.B4A9 (VBUS), U_3V3_LDO1.1 (VIN), U_3V3_LDO1.3 (CE)
unnamed: SW_V24_USB1.3, U_3V3_LDO1.5 (VOUT)
unnamed: C_3V3_BULK1.1, C_3V3_BYP1.1, SW_V24_USB1.1, TP_3V3.1 (1_1), U_24V_3V3.3 (+Vo)

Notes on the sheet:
led_error
led_2
btn_minus
led_1
btn_plus
led_filter
led_auto
led_4
led_3

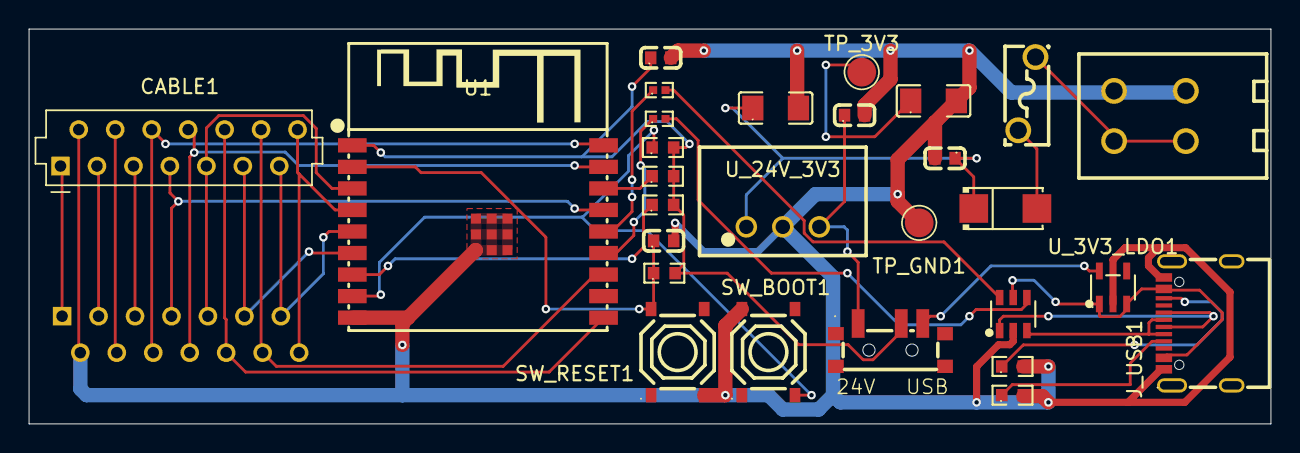
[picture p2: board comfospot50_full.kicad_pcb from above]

Board: 2 copper layers, 86.5 x 27.5 mm, 29 parts (1 on the bottom side), 33 nets.

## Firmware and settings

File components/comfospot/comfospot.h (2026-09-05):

#pragma once

// SPDX-FileCopyrightText: 2026 cornim
// SPDX-License-Identifier: GPL-3.0-or-later

#include <algorithm>
#include <cstdint>
#include <vector>

#include "esphome/components/binary_sensor/binary_sensor.h"
#include "esphome/components/button/button.h"
#include "esphome/components/fan/fan.h"
#include "esphome/components/select/select.h"
#include "esphome/components/sensor/sensor.h"
#include "esphome/core/component.h"
#include "esphome/core/gpio.h"
#include "esphome/core/preferences.h"

#include "comfospot_protocol.h"

namespace esphome::comfospot {

class ComfoSpot final : public Component {
 public:
  enum class Direction : uint8_t {
    EXCHANGE = 0,
    INTAKE = 1,
    EXHAUST = 2,
    UNKNOWN = 255,
  };

  void set_led_1_pin(GPIOPin *pin) { this->led_1_pin_ = pin; }
  void set_led_2_pin(GPIOPin *pin) { this->led_2_pin_ = pin; }
  void set_led_3_pin(GPIOPin *pin) { this->led_3_pin_ = pin; }
  void set_led_4_pin(GPIOPin *pin) { this->led_4_pin_ = pin; }
  void set_filter_pin(GPIOPin *pin) { this->filter_pin_ = pin; }
  void set_error_pin(GPIOPin *pin) { this->error_pin_ = pin; }
  void set_auto_pin(GPIOPin *pin) { this->auto_pin_ = pin; }
  void set_plus_pin(GPIOPin *pin) { this->plus_pin_ = pin; }
  void set_minus_pin(GPIOPin *pin) { this->minus_pin_ = pin; }

  void setup() override;
  void loop() override;
  void dump_config() override;
  void on_shutdown() override;
  float get_setup_priority() const override { return setup_priority::HARDWARE; }

  void set_fan(fan::Fan *fan) {
    if (std::find(this->fans_.begin(), this->fans_.end(), fan) != this->fans_.end()) {
      ESP_LOGW("comfospot", "Fan entity registered more than once");
      return;
    }
    this->fans_.push_back(fan);
    if (this->initialized_)
      this->sync_fan_();
  }
  void set_speed_sensor(sensor::Sensor *sensor) {
    if (std::find(this->speed_sensors_.begin(), this->speed_sensors_.end(), sensor) != this->speed_sensors_.end()) {
      ESP_LOGW("comfospot", "Speed sensor registered more than once");
      return;
    }
    this->speed_sensors_.push_back(sensor);
    if (this->initialized_)
      this->publish_speed_sensor_();
  }
  void set_runtime_sensor(sensor::Sensor *sensor) {
    if (std::find(this->runtime_sensors_.begin(), this->runtime_sensors_.end(), sensor) != this->runtime_sensors_.end()) {
      ESP_LOGW("comfospot", "Runtime sensor registered more than once");
      return;
    }
    this->runtime_sensors_.push_back(sensor);
    if (this->initialized_)
      this->publish_runtime_sensor_();
  }
  void set_filter_sensor(binary_sensor::BinarySensor *sensor) {
    if (std::find(this->filter_sensors_.begin(), this->filter_sensors_.end(), sensor) != this->filter_sensors_.end()) {
      ESP_LOGW("comfospot", "Filter sensor registered more than once");
      return;
    }
    this->filter_sensors_.push_back(sensor);
    if (this->initialized_)
      this->publish_status_sensors_();
  }
  void set_error_sensor(binary_sensor::BinarySensor *sensor) {
    if (std::find(this->error_sensors_.begin(), this->error_sensors_.end(), sensor) != this->error_sensors_.end()) {
      ESP_LOGW("comfospot", "Error sensor registered more than once");
      return;
    }
    this->error_sensors_.push_back(sensor);
    if (this->initialized_)
      this->publish_status_sensors_();
  }
  void set_auto_sensor(binary_sensor::BinarySensor *sensor) {
    if (std::find(this->auto_sensors_.begin(), this->auto_sensors_.end(), sensor) != this->auto_sensors_.end()) {
      ESP_LOGW("comfospot", "Automatic-mode sensor registered more than once");
      return;
    }
    this->auto_sensors_.push_back(sensor);
    if (this->initialized_)
      this->publish_status_sensors_();
  }
  void set_direction_select(select::Select *select) {
    if (std::find(this->direction_selects_.begin(), this->direction_selects_.end(), select) != this->direction_selects_.end()) {
      ESP_LOGW("comfospot", "Direction select registered more than once");
      return;
    }
    this->direction_selects_.push_back(select);
    if (this->initialized_)
      this->publish_direction_();
  }

  void request_speed(int speed);
  void request_direction(Direction direction);
  void reset_filter();

  int current_speed() const { return this->current_speed_; }
  bool speed_known() const { return this->speed_known_; }
  int preferred_speed() const { return this->last_active_speed_; }
  Direction current_direction() const { return this->direction_; }
  bool filter_change_needed() const { return this->filter_latched_; }
  bool error_active() const { return this->error_latched_; }
  bool auto_active() const { return this->auto_latched_; }
  uint32_t filter_runtime_seconds() const;
  float filter_runtime_days() const;

 protected:
  struct PanelSample {
    uint8_t led_mask{0};
    bool filter{false};
    bool error{false};
    bool auto_mode{false};
    bool plus{false};
    bool minus{false};
  };

  struct PhysicalButtonState {
    bool raw{false};
    bool stable{false};
    bool pressed{false};
    uint32_t raw_changed_at{0};
    uint32_t press_started_at{0};
    bool started_with_display_off{false};
  };

  enum class Operation : uint8_t {
    IDLE,
    WAIT_PANEL_OFF,
    SPEED_WAKE_PRESS,
    SPEED_WAKE_WAIT,
    SPEED_STEP_PRESS,
    SPEED_STEP_WAIT,
    SPEED_CONFIRM,
    MODE_HOLD_WAIT,
    MODE_HOLD,
    MODE_CONFIRM,
    POST_OPERATION_OFF,
    FILTER_WAIT_OFF,
    FILTER_WAKE_PRESS,
    FILTER_WAKE_RELEASE,
    FILTER_HOLD,
    FILTER_CONFIRM,
  };
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

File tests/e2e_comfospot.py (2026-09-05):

#!/usr/bin/env python3
# SPDX-FileCopyrightText: 2026 cornim
# SPDX-License-Identifier: GPL-3.0-or-later

"""Live ESPHome API end-to-end tests for the ComfoSpot component.

The test runner deliberately keeps credentials outside the repository. Use
COMFOSPOT_HOST and ESPHOME_API_KEY, or pass --host and --api-key. The API key
is never printed or written to an artifact.

The default suite exercises operations that can be driven through the native
ESPHome API and works with firmware configured at logger level INFO.
"""

from __future__ import annotations

import argparse
import asyncio
import contextlib
from dataclasses import asdict, dataclass, field
import fnmatch
import json
import math
import os
from pathlib import Path
import time
from typing import Any, Awaitable, Callable

try:
    from aioesphomeapi import (
        APIClient,
        BinarySensorInfo,
        ButtonInfo,
        EntityInfo,
        EntityState,
        FanInfo,
        LogLevel,
        SelectInfo,
        SensorInfo,
    )
except ImportError as exc:  # pragma: no cover - exercised by the CLI
    raise SystemExit(
        "aioesphomeapi is required; install it with 'python3 -m pip install -r requirements-dev.txt'"
    ) from exc


STANDBY_SETTLE_SECONDS = 30.0
OPERATION_SETTLE_SECONDS = 12.0


class TestFailure(Exception):
    """A live assertion failed."""


@dataclass
class TestResult:
    test_id: str
    title: str
    status: str
    duration_s: float
    message: str = ""
    evidence: dict[str, Any] = field(default_factory=dict)


@dataclass
class Case:
    test_id: str
    title: str
    run: Callable[[], Awaitable[dict[str, Any]]]


class LiveSuite:
    """State, log, entity, and command helpers for one API connection."""

    def __init__(self, host: str, api_key: str, port: int, output: Path, verbose: bool) -> None:
        self.host = host
        self.client = APIClient(
            host,
            port,
            client_info="comfospot-e2e-tests",
            noise_psk=api_key,
        )
        self.output = output
        self.verbose = verbose
        self.entities: list[EntityInfo] = []
        self.entity_by_id: dict[str, EntityInfo] = {}
        self.state_by_key: dict[tuple[int, int], EntityState] = {}
        self.states_changed = asyncio.Event()
        self.logs: list[dict[str, Any]] = []
        self.log_changed = asyncio.Event()
        self.log_unsubscribe: Callable[[], None] | None = None
        self.device_info: Any = None
        self.keys: dict[str, int] = {}
        self.last_case_log_index = 0

    async def connect(self) -> None:
        await self.client.connect(login=False)
        self.device_info, self.entities, _ = await self.client.device_info_and_list_entities()
        self.entity_by_id = {entity.object_id: entity for entity in self.entities if entity.object_id}
        self._resolve_entities()
        self.log_unsubscribe = self.client.subscribe_logs(
            self._on_log,
            log_level=LogLevel.LOG_LEVEL_INFO,
            dump_config=False,
        )
        self.client.subscribe_states(self._on_state)
        await asyncio.sleep(1.0)

    async def close(self) -> None:
        with contextlib.suppress(Exception):
            self.client.subscribe_logs(lambda _: None, log_level=LogLevel.LOG_LEVEL_NONE)
        if self.log_unsubscribe is not None:
            self.log_unsubscribe()
            self.log_unsubscribe = None
        with contextlib.suppress(Exception):
            await self.client.disconnect()

    def _resolve_entities(self) -> None:
        fan = self._one(FanInfo)
        select = self._one(SelectInfo)
        if fan is not None:
            self.keys["fan"] = fan.key
        if select is not None:
            self.keys["direction"] = select.key

        for entity in self.entities:
            name = f"{entity.name} {entity.object_id}".lower()
            if isinstance(entity, SensorInfo):
                if "current fan speed" in name or "current_fan_speed" in name:
                    self.keys["current_speed"] = entity.key
                elif "filter runtime" in name or "filter_runtime" in name:
                    self.keys["filter_runtime"] = entity.key
            elif isinstance(entity, BinarySensorInfo):
                if "change filter" in name or "filter_change" in name:
                    self.keys["filter"] = entity.key
                elif "error" in name:
                    self.keys["error"] = entity.key
                elif "automatic" in name or "auto" in name:
                    self.keys["auto"] = entity.key
            elif isinstance(entity, ButtonInfo) and (
                "reset filter" in name or "reset_filter" in name
            ):
                self.keys["reset_filter"] = entity.key

        required = ("fan", "current_speed", "direction")
        missing = [name for name in required if name not in self.keys]
        if missing:
            raise TestFailure(f"Required entities were not discovered: {', '.join(missing)}")

    def _one(self, cls: type[EntityInfo]) -> EntityInfo | None:
        matches = [entity for entity in self.entities if isinstance(entity, cls)]
        return matches[0] if matches else None

    def _on_state(self, state: EntityState) -> None:
        self.state_by_key[(state.device_id, state.key)] = state
        self.states_changed.set()

    def _on_log(self, message: Any) -> None:
        text = message.message.decode("utf-8", "backslashreplace") if isinstance(message.message, bytes) else str(message.message)
        item = {
            "received_at": time.monotonic(),
            "level": int(message.level),
            "message": text,
        }
        self.logs.append(item)
        self.log_changed.set()
        if self.verbose:
            print(f"LOG[{message.level}] {text}")

    def entity_inventory(self) -> list[dict[str, Any]]:
        return [
            {
                "type": type(entity).__name__,
                "name": entity.name,
                "object_id": entity.object_id,
                "key": entity.key,
                "device_id": entity.device_id,
            }
            for entity in self.entities
        ]

    def state(self, name: str) -> EntityState | None:
        key = self.keys.get(name)
        if key is None:
            return None
        device_id = next((entity.device_id for entity in self.entities if entity.key == key), 0)
        return self.state_by_key.get((device_id, key)) or self.state_by_key.get((0, key))

    def state_value(self, name: str) -> Any:
        state = self.state(name)
        return getattr(state, "state", None) if state is not None else None

    async def wait_until(
        self,
        predicate: Callable[[], bool],
        timeout: float,
        description: str,
        interval: float = 0.1,
    ) -> None:
        deadline = time.monotonic() + timeout
        while True:
            if predicate():
                return
            remaining = deadline - time.monotonic()
            if remaining <= 0:
                raise TestFailure(f"Timed out waiting for {description}")
            self.states_changed.clear()
            self.log_changed.clear()
            try:
                await asyncio.wait_for(
                    asyncio.gather(self.states_changed.wait(), self.log_changed.wait()),
                    timeout=min(remaining, interval),
                )
            except asyncio.TimeoutError:
                pass

    async def wait_state(self, name: str, expected: Any, timeout: float = 20.0) -> None:
        await self.wait_until(
            lambda: self.state_value(name) == expected,
            timeout,
            f"{name}={expected!r} (last={self.state_value(name)!r})",
        )

    def begin_case(self) -> None:
        self.last_case_log_index = len(self.logs)

    def case_logs(self) -> list[str]:
        return [item["message"] for item in self.logs[self.last_case_log_index :]]

    def evidence(self) -> dict[str, Any]:
        return {
            "state": {name: self.state_value(name) for name in self.keys},
            "logs": self.case_logs()[-80:],
        }

    async def fan(self, speed: int) -> None:
        log_start = len(self.logs)
        current_speed = self.state_value("current_speed")
        if speed == 0 and self.state_value("fan") is False and (
            current_speed == 0 or isinstance(current_speed, float) and math.isnan(current_speed)
        ):
            return
        if speed != 0 and current_speed == speed and self.state_value("fan") is True:
            return
        if speed == 0:
            self.client.fan_command(self.keys["fan"], state=False)
        else:
            self.client.fan_command(self.keys["fan"], state=True, speed_level=speed)
        failure_markers = (
            "Panel did not confirm requested fan speed",
            "Panel did not show a valid speed after wake-up",
            "Panel did not identify standby or active speed after wake-up",
            "Panel did not finish standby wake-up",
            "Panel operation exceeded its safety timeout",
        )
        await self.wait_until(
            lambda: self.state_value("current_speed") == speed
            or any(any(marker in item["message"] for marker in failure_markers) for item in self.logs[log_start:]),
            100.0,
            f"speed operation {speed}",
        )
        # The speed entity is published optimistically after each button press.
        # At logger level INFO there is no DEBUG confirmation message, so wait
        # through the final panel confirmation and dark-panel barrier here.
        await asyncio.sleep(OPERATION_SETTLE_SECONDS)
        if any(any(marker in item["message"] for marker in failure_markers) for item in self.logs[log_start:]):
            failure = next(
                (item["message"] for item in self.logs[log_start:] if any(marker in item for marker in failure_markers)),
                "Panel did not confirm requested fan speed",
            )
            raise TestFailure(failure)
        await self.wait_state("current_speed", speed, timeout=5.0)

    async def direction(self, direction: str) -> None:
        log_start = len(self.logs)
        self.client.select_command(self.keys["direction"], direction)
        failure_markers = (
            "Panel did not confirm requested direction",
            "Panel did not finish wake-up before direction change",
            "ComfoSpot rejected intake mode",
            "Cannot select exchange while panel direction is unknown",
        )
        await self.wait_until(
            lambda: self.state_value("direction") == direction
            or any(any(marker in item["message"] for marker in failure_markers) for item in self.logs[log_start:]),
            30.0,
            f"direction operation {direction}",
        )
        if any(any(marker in item["message"] for marker in failure_markers) for item in self.logs[log_start:]):
            failure = next(
                (item["message"] for item in self.logs[log_start:] if any(marker in item for marker in failure_markers)),
                "Panel did not confirm requested direction",
            )
            raise TestFailure(failure)
        await self.wait_state("direction", direction, timeout=5.0)
        # The direction select state is published only after the marker has
        # been accepted and the final dark-panel barrier has completed.

    async def wake_panel_before_direction(self) -> None:
        """Synchronize speed 2 before a mode command.

        The firmware owns the wake transaction and intentionally leaves the
        panel dark after confirming a command. A stable active display is not
        required before the next mode operation.
        """
        await self.fan(2)

    async def setup_exchange_speed(self, speed: int = 2) -> None:
        await self.fan(speed)
        current = self.state_value("direction")
        if current is None:
            await self.direction("Intake")
            await self.direction("Exchange")
        elif current != "Exchange":
            await self.direction("Exchange")

    async def safe_off(self) -> None:
        if "fan" not in self.keys:
            return
        with contextlib.suppress(TestFailure, asyncio.TimeoutError):
            await self.fan(0)


class Runner:
    def __init__(
        self,
        suite: LiveSuite,
    ) -> None:
        self.suite = suite
        self.results: list[TestResult] = []

    def cases(self) -> list[Case]:
        cases: list[Case] = [
            Case("API-001", "Connect to the node", self.api_connect),
            Case("API-002", "Discover expected entities", self.api_entities),
            Case("API-003", "Subscribe to device logs", self.api_logs),
            Case("API-004", "Validate initial state consistency", self.api_initial_state),
            Case("API-006", "Verify no startup errors", self.api_startup_errors),
        ]
        cases.extend(
            [
                Case("FAN-STANDBY-SPEED-1", "Standby to speed 1 and back", lambda: self.fan_standby_cycle(1)),
                Case("FAN-STANDBY-SPEED-4", "Standby to speed 4 and back", lambda: self.fan_standby_cycle(4)),
            ]
        )
        cases.extend(
            [
                Case(
                    "DIR-PANEL-ON",
                    "All six direction transitions with panel on",
                    lambda: self.direction_condition("panel_on"),
                ),
                Case("RUN-001", "Runtime increases while active", self.runtime_active),
                Case("RUN-002", "Runtime does not increase while standby", self.runtime_standby),
                Case("RUN-003", "Runtime survives speed changes", self.runtime_speed_changes),
                Case("RUN-008", "API reconnect", self.api_reconnect),
            ]
        )
        return cases

    def selected_cases(self, patterns: list[str] | None) -> list[Case]:
        cases = self.cases()
        if not patterns:
            return cases
        selected = [
            case
            for case in cases
            if any(
                fnmatch.fnmatchcase(case.test_id, pattern)
                or fnmatch.fnmatchcase(case.title.lower(), pattern.lower())
                for pattern in patterns
            )
        ]
        if not selected:
            raise TestFailure(f"No tests matched: {', '.join(patterns)}")
        return selected

    async def run(self, patterns: list[str] | None = None) -> None:
        for case in self.selected_cases(patterns):
            self.suite.begin_case()
            started = time.monotonic()
            try:
                evidence = await case.run()
                status = "PASS"
                message = ""
            except (TestFailure, AssertionError, asyncio.TimeoutError) as exc:
                status = "FAIL"
                message = str(exc) or type(exc).__name__
                evidence = self.suite.evidence()
            except Exception as exc:  # keep the rest of the suite observable
                status = "ERROR"
                message = f"{type(exc).__name__}: {exc}"
                evidence = self.suite.evidence()
            duration = time.monotonic() - started
            result = TestResult(case.test_id, case.title, status, duration, message, evidence)
            self.results.append(result)
            print(
                f"{status:5} {case.test_id:22} {case.title} ({duration:.1f}s)"
                f"{f': {message}' if message else ''}",
                flush=True,
            )

    async def api_connect(self) -> dict[str, Any]:
        if self.suite.device_info is None:
            raise TestFailure("Device information was not received")
        return {"device_name": self.suite.device_info.name, "connected_address": self.suite.host}

    async def api_entities(self) -> dict[str, Any]:
        required = {"fan", "current_speed", "direction"}
        optional = {"filter", "error", "auto", "filter_runtime"}
        missing = required - self.suite.keys.keys()
        if missing:
            raise TestFailure(f"Missing required entity keys: {sorted(missing)}")
        return {"keys": self.suite.keys, "optional_missing": sorted(optional - self.suite.keys.keys()), "entities": self.suite.entity_inventory()}

    async def api_logs(self) -> dict[str, Any]:
        await asyncio.sleep(1.0)
        if not self.suite.logs:
            raise TestFailure("No device log messages received")
        return {"log_messages": len(self.suite.logs), "levels": sorted({item["level"] for item in self.suite.logs})}

    async def api_initial_state(self) -> dict[str, Any]:
        speed = self.suite.state_value("current_speed")
        if speed is not None and not (isinstance(speed, float) and math.isnan(speed)) and not 0 <= speed <= 4:
            raise TestFailure(f"Invalid initial speed {speed}")
        if speed is None:
            raise TestFailure("No initial speed state was received")
        return self.suite.evidence()

    async def api_startup_errors(self) -> dict[str, Any]:
        errors = [
            text
            for text in self.suite.case_logs()
            if "Required panel GPIOs are not configured" in text or "Panel operation exceeded" in text
        ]
        if errors:
            raise TestFailure("Startup/runtime errors observed: " + " | ".join(errors))
        return {"errors": errors}

    async def fan_standby_cycle(self, target: int) -> dict[str, Any]:
        await self.suite.fan(0)
        await self.suite.wait_state("fan", False, timeout=15.0)
        await asyncio.sleep(STANDBY_SETTLE_SECONDS)
        await self.suite.fan(target)
        await self.suite.fan(0)
        return {"target": target, **self.suite.evidence()}

    async def direction_condition(self, condition: str) -> dict[str, Any]:
        if condition != "panel_on":
            raise TestFailure(f"Unsupported direction condition {condition!r}")
        transitions = (
            ("Exchange", "Exhaust"),
            ("Exhaust", "Exchange"),
            ("Exchange", "Intake"),
            ("Intake", "Exchange"),
            ("Exhaust", "Intake"),
            ("Intake", "Exhaust"),
        )
        transition_results: list[dict[str, Any]] = []
        for source, target in transitions:
            await self.suite.wake_panel_before_direction()
            await self.ensure_direction(source)

            await self.suite.direction(target)
            transition_results.append(
                {
                    "source": source,
                    "target": target,
                    "final_direction": self.suite.state_value("direction"),
                }
            )
            if self.suite.state_value("direction") != target:
                raise TestFailure(
                    f"Direction transition {source}->{target} ended at "
                    f"{self.suite.state_value('direction')!r}"
                )
        return {
            "condition": condition,
            "transitions": transition_results,
            **self.suite.evidence(),
        }

    async def ensure_direction(self, direction: str) -> None:
        current = self.suite.state_value("direction")
        if current == direction:
            return
        if current not in ("Exchange", "Intake", "Exhaust") and direction == "Exchange":
            # Exchange is intentionally rejected while the firmware has no
            # direction evidence. Establish a safe known direction first,
            # then use the normal marker-based transition back to Exchange.
            await self.suite.direction("Intake")
            current = self.suite.state_value("direction")
        if current != direction:
            await self.suite.direction(direction)


    async def runtime_active(self) -> dict[str, Any]:
        if "filter_runtime" not in self.suite.keys:
            raise TestFailure("Filter Runtime sensor is not present")
        await self.suite.fan(2)
        first = self.suite.state_value("filter_runtime")
        await asyncio.sleep(3.0)
        second = self.suite.state_value("filter_runtime")
        if first is None or second is None or second <= first:
            raise TestFailure(f"Runtime did not increase while active: {first!r} -> {second!r}")
        return {"before": first, "after": second, **self.suite.evidence()}

    async def runtime_standby(self) -> dict[str, Any]:
        if "filter_runtime" not in self.suite.keys:
            raise TestFailure("Filter Runtime sensor is not present")
        await self.suite.fan(0)
        first = self.suite.state_value("filter_runtime")
        await asyncio.sleep(3.0)
        second = self.suite.state_value("filter_runtime")
        if first is None or second is None or second != first:
            raise TestFailure(f"Runtime changed while standby: {first!r} -> {second!r}")
        return {"before": first, "after": second, **self.suite.evidence()}

    async def runtime_speed_changes(self) -> dict[str, Any]:
        if "filter_runtime" not in self.suite.keys:
            raise TestFailure("Filter Runtime sensor is not present")
        await self.suite.fan(1)
        first = self.suite.state_value("filter_runtime")
        await self.suite.fan(4)
        await asyncio.sleep(2.0)
        second = self.suite.state_value("filter_runtime")
        if first is None or second is None or second < first:
            raise TestFailure(f"Runtime regressed across speed change: {first!r} -> {second!r}")
        return {"before": first, "after": second, **self.suite.evidence()}
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

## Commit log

2026-09-05 Initial ComfoSpot 50 integration
    [bom.csv, comfospot50_full.kicad_pcb, comfospot50_full.kicad_sch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]
2026-09-07 Reduce filter runtime update frequency
2026-09-07 Add C20252913 connector to hardware design
    [bom.csv, comfospot50_full.kicad_pcb, comfospot50_full.kicad_sch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]
2026-09-07 Normalize JLC library references
    [comfospot50_full.kicad_pcb, comfospot50_full.kicad_sch]
2026-09-07 Use GitHub component in ESPHome example
    [comfospot50_full.kicad_sch]
2026-09-07 Remove disallowed hardware metadata
    [comfospot50_full.kicad_pcb, comfospot50_full.kicad_sch]
2026-11-01 Fix direction markers being interpreted as fan speed
